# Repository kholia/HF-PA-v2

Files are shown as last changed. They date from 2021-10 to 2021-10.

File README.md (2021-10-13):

### HF-PA-v2

VU3CER's `Class-E HF PA` for https://github.com/kholia/Easy-Digital-Beacons-v1
project for 20m band and up. It has (optional) software-controlled variable PA
Output Power.

Supported bands: 80, 60, 40, 30, 20, 17m, and more bands with switchable 'LPF
Module' board.

(July 2021 Update): While this HF PA works as well as the uSDX V1.02 PA and the
QCX+ PA (they all use the same design!), we prefer our new [HF-PA-v3
system](https://github.com/kholia/HF-PA-v3/) PA for its robustness. If you
need a 3W+ @ 14 MHz with high efficiency, this Class-E HF PA design
(`HF-PA-v2`) is the best one ;)

Constraints for the initial PCB prototypes for validating the design:

- PCB is to be homebrewed (laser printer, toner tranfer using iron, etching via FeCl3)

- PCB is single-sided. Only one layer is available for routing.

- BS170 MOSFETs need to be on an edge to allow usage of heatsinks.

- My external `PA150 HF Linear Amplifier` needs 2W minimum to function.

Input: Few milliwatts is fine. Note: Si5351's output is around 8-10mW.

Output: Full-power 3.2W+ @ 13.3v (4S LiFePo4) for 20m band (14.074 MHz) with
around 45-55% efficiency *OR* Safer 2W with reasonable PWM setting for digital
modes!

Note: All screenshots are clickable and zoomable.

Note 2: Active cooling (fan) is recommended for digital modes! You have been
informed ;)

Schematic:

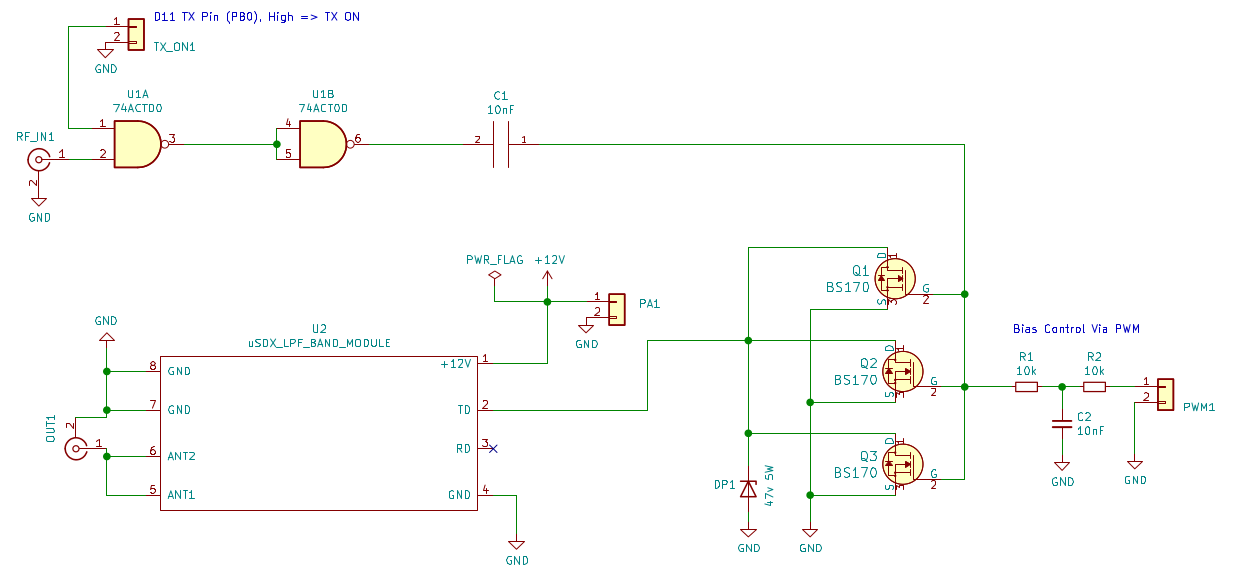
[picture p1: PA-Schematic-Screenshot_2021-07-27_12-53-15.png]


The HF PA has over-voltage ("High-SWR") protection via a `47v zener power-dumping diode`.

PCB renderings:

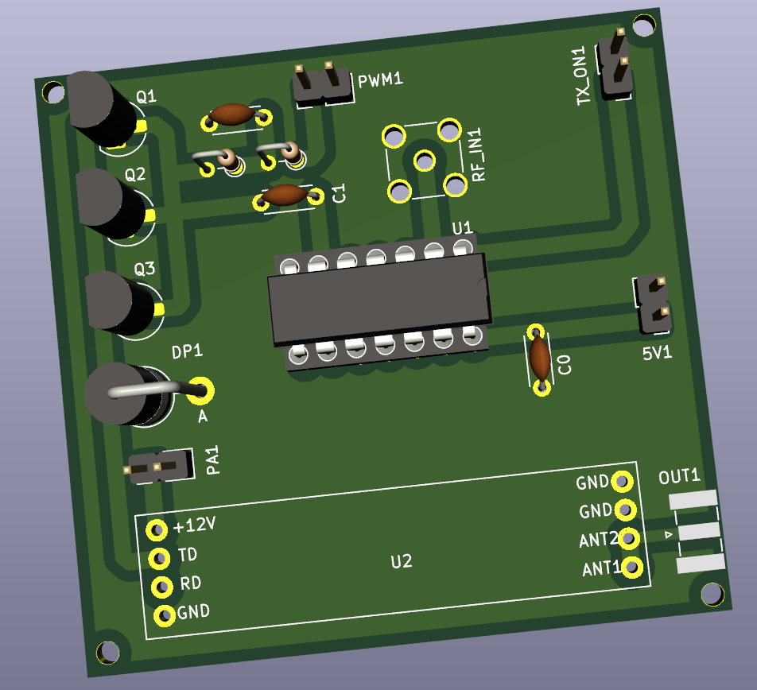
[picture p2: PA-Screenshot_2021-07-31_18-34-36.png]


Socketable version (recommended):

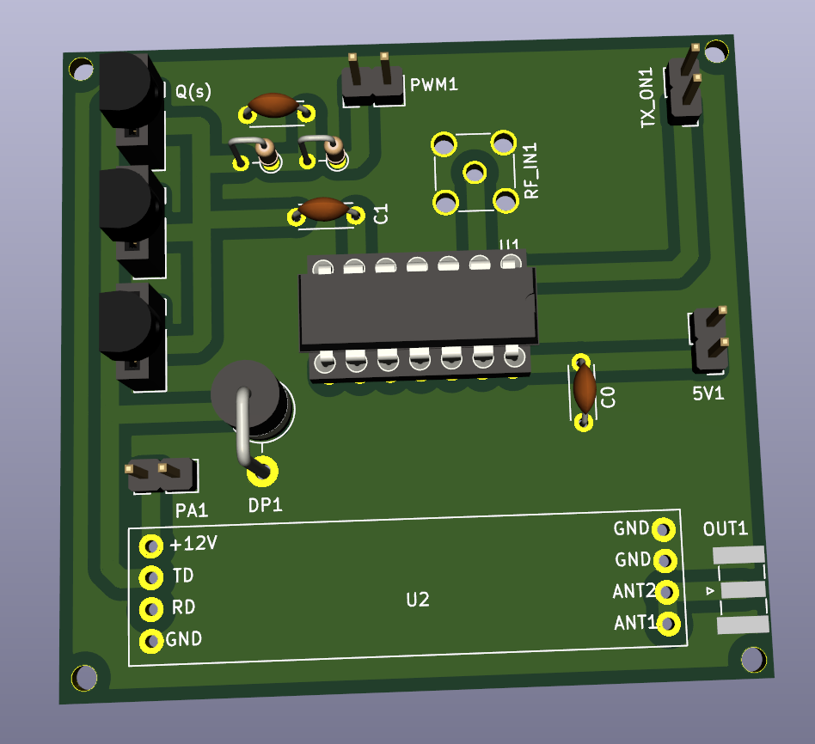
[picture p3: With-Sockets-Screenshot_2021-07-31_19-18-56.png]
HF-PA-v1 Sockets


Testing the Triple-Mode PSU + LPF 20m + 3xBS170 @ 13.8v:

HF-PA-v1 Demo
HF-PA-v1 Demo 2

LPF schematic (from uSDX PCB by WB2CBA):

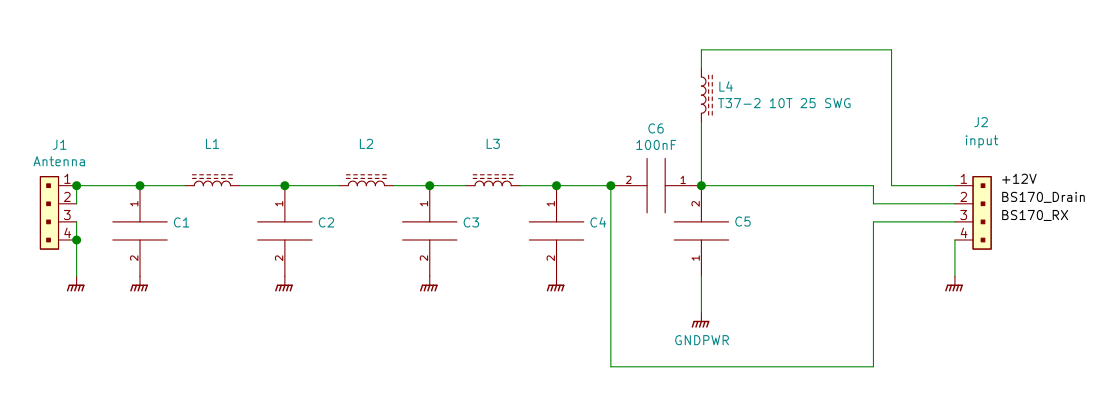
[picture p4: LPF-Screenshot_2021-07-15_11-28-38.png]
LPF 1


Safe power supply module for the PA. It has over-current protection.

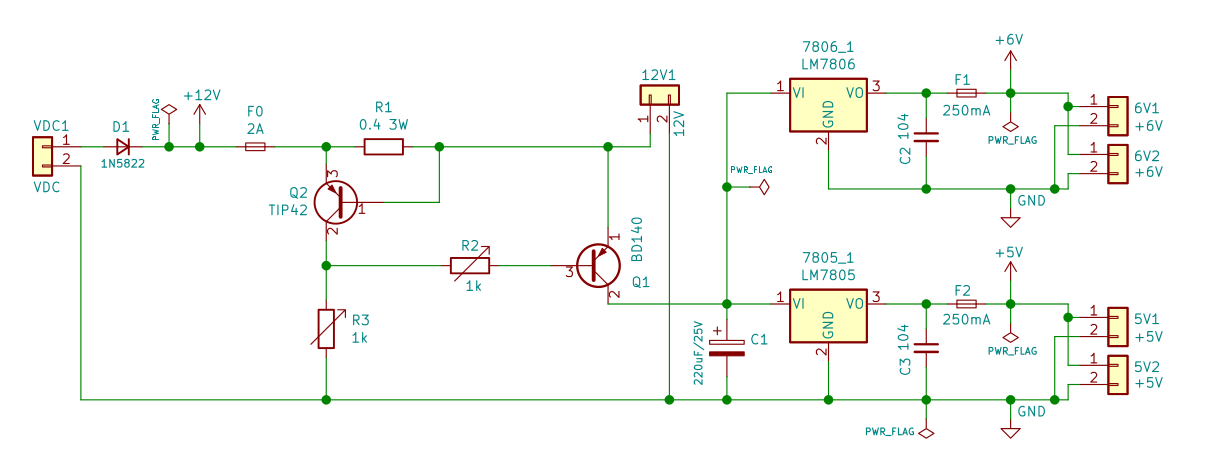
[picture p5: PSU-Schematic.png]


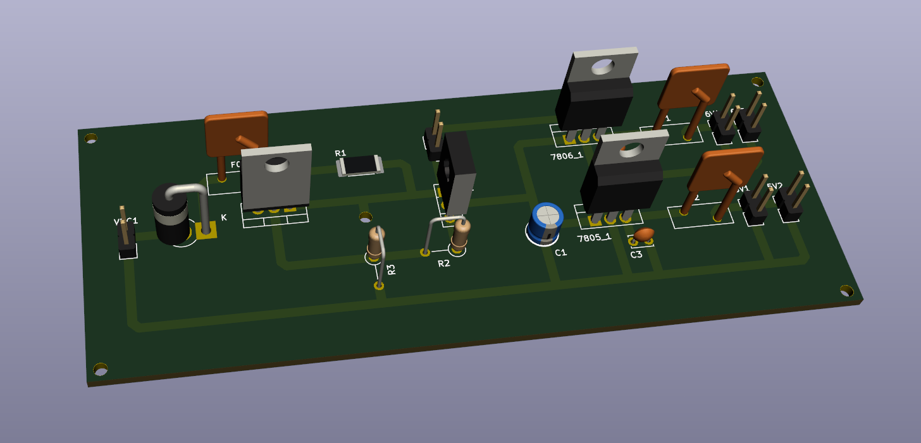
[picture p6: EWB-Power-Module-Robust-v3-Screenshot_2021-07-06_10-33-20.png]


Note: This 3D rendering is *only* published to help with the manual layout work
on Zero-PCBs.

Note 2: Various sub-circuits were simulated in LTspice prior to implementation.

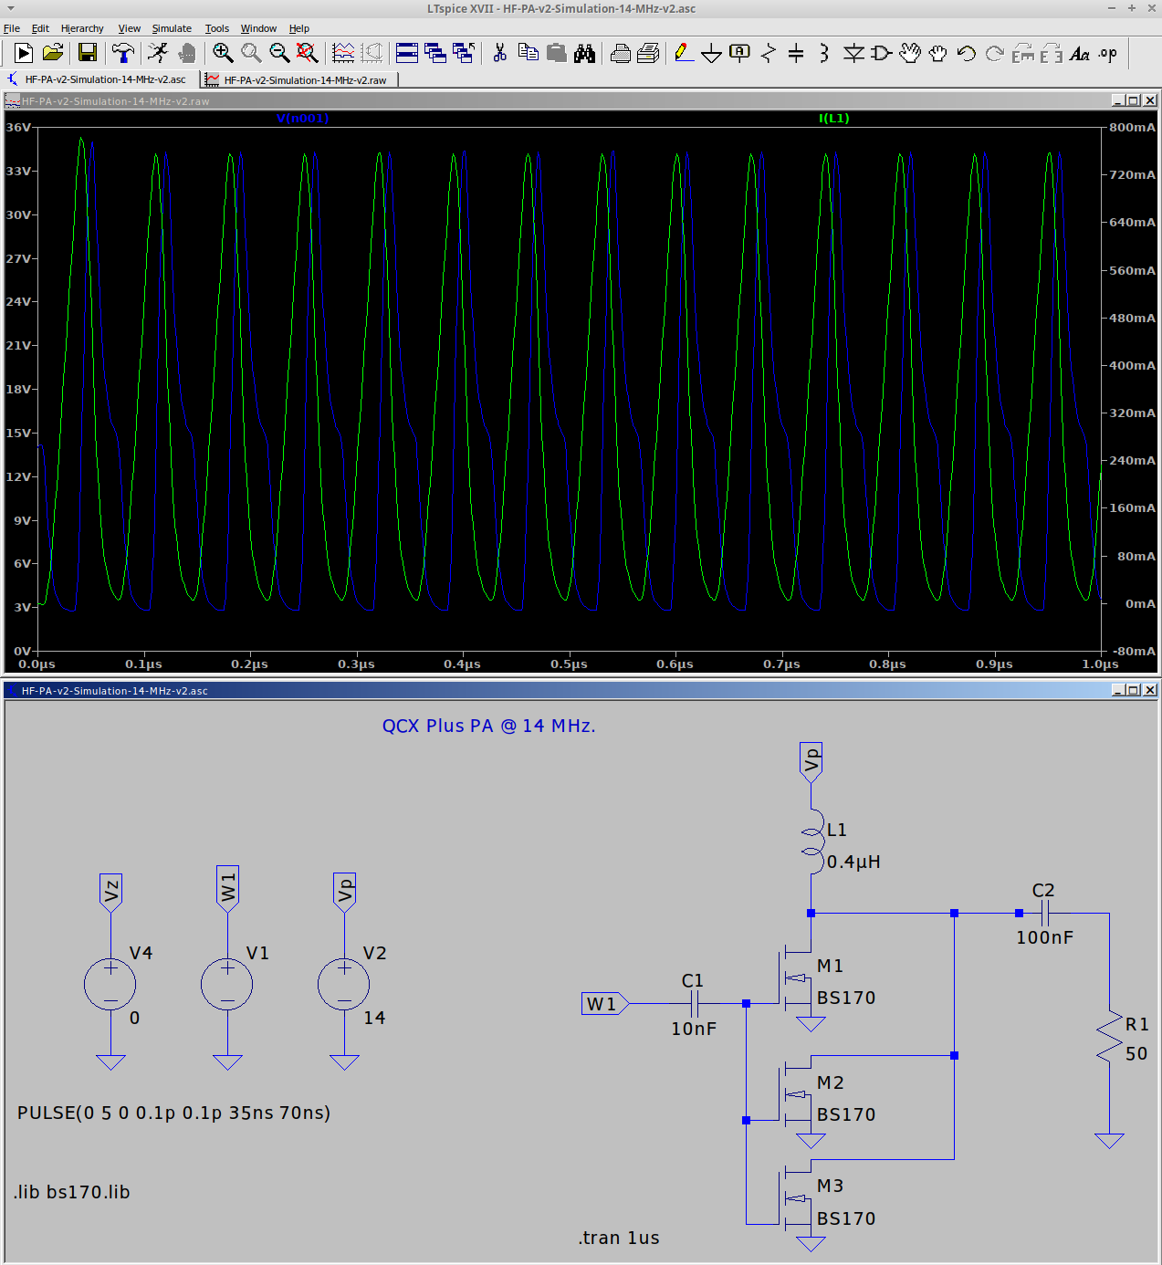
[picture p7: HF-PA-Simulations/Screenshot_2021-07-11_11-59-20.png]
Simulation 0

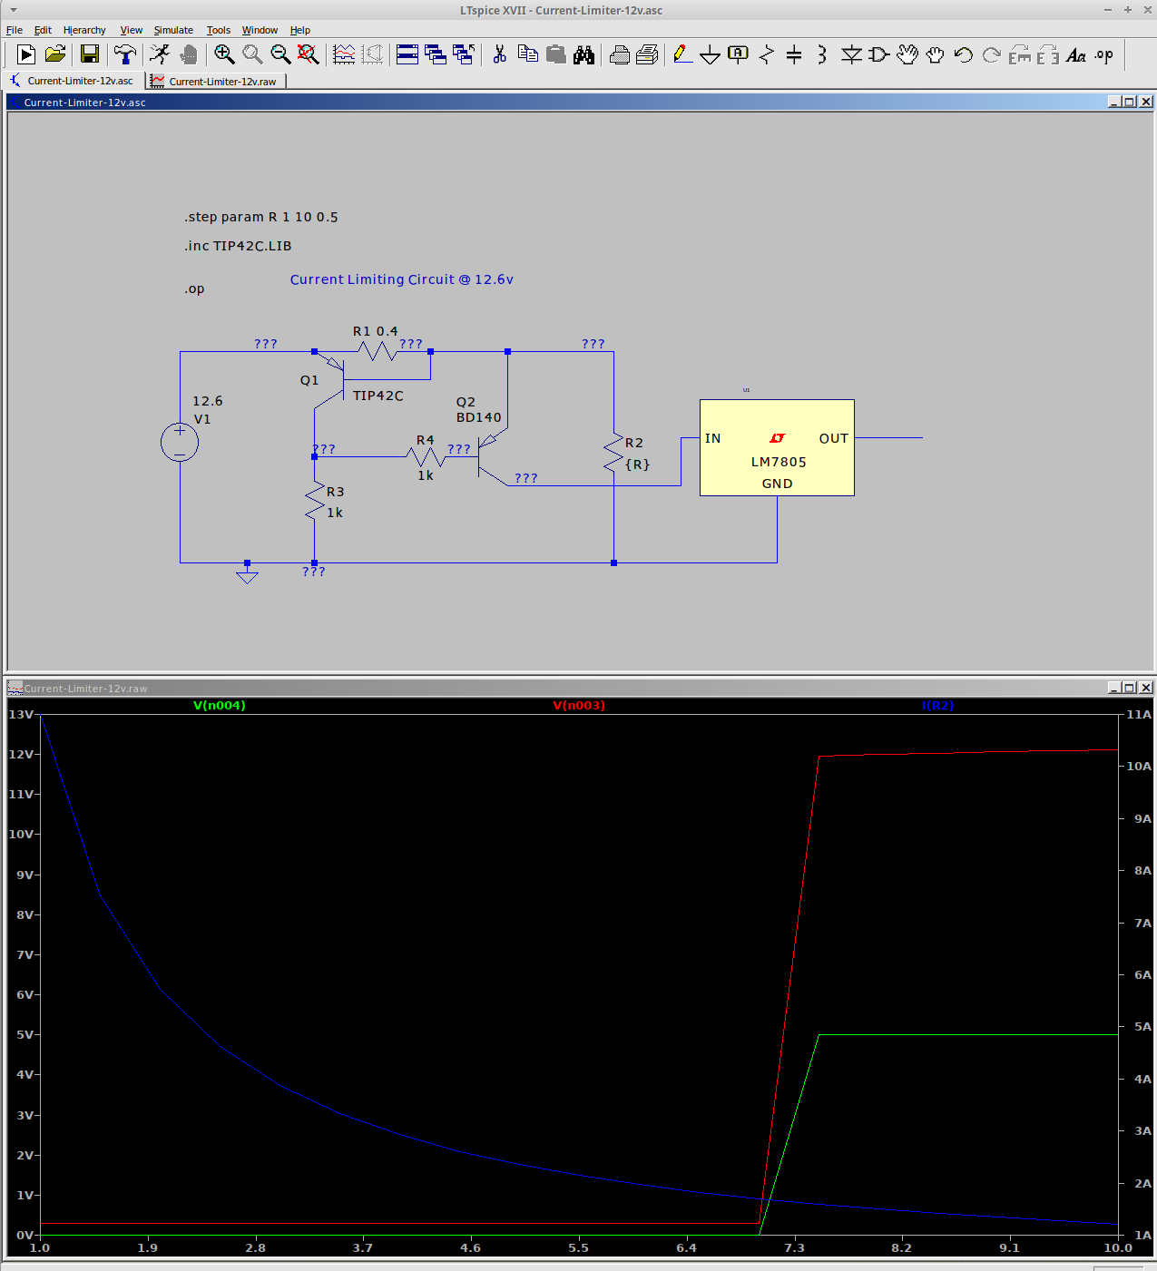
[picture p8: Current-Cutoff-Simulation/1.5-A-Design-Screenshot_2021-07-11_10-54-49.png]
Simulation 1


### Sample Code

- https://github.com/kholia/uSDX_Beacon

- https://github.com/kholia/Easy-Digital-Beacons-v1

#### O(Current consumption)

The ESP8266 usually draws a peak current of about 250mA after it wakes up and
then more or less constantly draws around 70mA before it goes back to sleep.

DS3231 -> 5mA

Si5351 -> ~50 to 100mA

Upper bound -> 1.4A maximum.

#### BOM

- 1 x SN74ACT00N (TI)

- 3 x BS170 (ON Semi)

- 1 x 7805 Voltage Regulator TO-220 (STMicroelectronics)

- 1 x 7806 Voltage Regulator TO-220 (STMicroelectronics)

- 1 x 1N5822

- 1 x 1N5368B (47V 5W Zener Diode)

- 2 x 0.2 Ohms - 3W Current Sensing Resistor

- 2 x 1k Ohm - 0.25W Metal Film Resistor

- 220uF 25v Electrolytic Capacitor

- 5 x 100nF (104) Ceramic Capacitor

- 1 x 10nF (103) Ceramic Capacitor

- 1 x BD140 Transistor

- 1 x TIP42 Darlington Transistor

- 3 x T37-6 - Yellow Toroid, 1 x T37-2 - Red Toroid (LPF)

- 2 x 180pf, 2 x 390pf, 1 x 30pF NP0 Ceramic Capacitors (LPF caps, Kemet)

- 3 meters - Copper Magnetic Winding Wire (24 AWG - 25 SWG)

- Misc: Connectors, Zero PCB, Various Consumables

- Tools: LCR-T4 Meter (for measuring things), RF Power Meter

Tip: Buy in bulk for better pricing, and for getting spares for the "junk box".

#### 20m LPF Module Details

- L1 - T37-6 / 16 turns
- L2 - T37-6 / 17 turns
- L3 - T37-6 / 16 turns
- L4 - T37-2 / 10 turns
- C1 - 180pf
- C2 - 390pf
- C3 - 390pf
- C4 - 180pf
- C5 - 30pf

Borrowed from QCX manual and uSDX WB2CBA PCB documentation.

#### BOM + Equipment Sources

- https://www.semikart.com/ (BS170, NP0 LPF caps - Kemet and others, Aavid DIP-14/16 Heat Sinks)

- https://www.semikart.com/search/SN74ACT00N

- https://robu.in/product/0-2-ohm-3w-surface-mount-sense-resistor-pack-of-3/

- https://www.electronicscomp.com/

  - BS170, regular caps, ST voltage regulators

  - TIP42, BD140

- https://www.electroncomponents.com/ (transistors, connectors, consumables, misc)

- https://www.sunrom.com/ (regular ceramic caps)

- https://projectpoint.in/

  - Transistors, regular caps, voltage regulators, MFR resistors, misc

  - Copper Magnetic Winding Wire

- https://www.bhagwatilightingindustries.com (Thermal Adhesive Paste)

- https://www.sunrom.com/p/254mm-40x1-female-socket-strip-machine-round-pins

  `SIP Sockets 1A`

- eBay (`gr_makis`) - Toroids

- [LCR-T4 LCR Meter](https://www.techtonics.in/lcr-t4-12864-lcd-graphical-transistor-tester-resistance-capacitance-esr-scr-meter)

### Notes

- The `CDIL 2N3904` TO-92 transistor has `CT2N 3904 LS` marking on it.

  `CT` -> `Continental... Device India Ltd (CDIL)`

- `Burnt` BS170 MOSFETs typically have their `Drain` and `Gate` shorted (Pin 1 and Pin 2 respectively).

- Use `SIP sockets` to avoid accidentally killing the MOSFETs via ESD (during probing, soldering, etc).

- PCB test: Remove the MOSFETS (keep everything else connected) and measure the
  resistance between the `Gate Pin` and `Ground`. It should show `OL (Open Line)`.

### Tips

- BS170 MOSFETs are very sensitive with regards to ESD and high soldering
  temperatures.

  Use best practices when dealing with BS170 MOSFETs and perhaps always ;)

#### References

- https://github.com/kholia/uSDX_Beacon
- https://github.com/agustinmartino/wsjt_transceiver
- http://hyse.org/pdf/www.aoc.nrao.edu/~pharden/hobby/_ClassDEF1.pdf
- http://hyse.org/pdf/www.aoc.nrao.edu/~pharden/hobby/_ClassDEF2.pdf
- http://thestone.zone/radio/2020/12/13/multi-watt-amplifier.html
- http://thestone.zone/radio/2020/12/18/gate-driver-amplifier.html
- http://thestone.zone/radio/2021/01/14/capacitors.html
- http://thestone.zone/radio/2021/01/16/minor-enhancements.html
- https://www.g0kla.com/scpa/SimpleCheapPA.php
- https://www.linkedin.com/pulse/rf-pcb-design-rules-manufacturing-process-lisa-chu/
- http://thestone.zone/radio/2021/06/04/attenuator.html
- http://thestone.zone/radio/2021/06/05/power-amplifier.html
- https://on7dq.blogspot.com/2020/12/qcx-mini-measurements.html
- https://www.random-science-tools.com/electronics/dBm-Watts-volts.htm
- https://www.mitsubishielectric.com/semiconductors/php/oSearch.php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
- http://www.carnut.info/WSPR_Tx/WSPR_Tx.htm
- https://sites.google.com/view/andy-g0ftd/iron-fist-transmitter
- https://www.dj0abr.de/english/technik/dds/pa.htm
- https://www.qsl.net/py2ohh/
- https://hf5l.pl/en/transceiver-usdx-with-arduino-nano/#

#### Credits

- MTR5B schematic
- PFR-3 design
- Dan Tayloe, N7VE (NC2030 PA design)
- Hans Summers (QCX+)
- Guido PE1NNZ (uSDX)
- WB2CBA (uSDX PCB)
- Tom (AK2B)
- Various uSDX folks
- Chris (G0KLA / AC2CZ) - over-current protection

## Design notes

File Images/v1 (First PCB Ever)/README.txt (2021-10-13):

"Print mirrored" was accidentally selected in KiCad! ;(

RF output for 11.5 drain voltage and 1xBS170 is ~0.5W (same as uSDX V1.02 board)

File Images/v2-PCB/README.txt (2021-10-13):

TIP: When doing a 'Zone Fills' ("ground copper pour"), increase the default
track clearance from 0.508 to 1.016. This helps a lot with homebrewing PCBs.

The "PCB v2" version uses this.

Note: (BS170) MOSFETs are easy to destroy via ESD! Using SIP sockets + a single
power supply source help in not destroying MOSFETs via ESD!

The "PCB v3" will use SIP sockets!

Use 0.8mm drill bit for making holes. Only the PCB Mount SMA connector requires
bigger drill holes.

python2 OscScreenGrabLAN.py png 192.168.1.15

Ignore the "common noise" superimposed on the output RF sine wave - we will
use better probing techniques in the future ;)

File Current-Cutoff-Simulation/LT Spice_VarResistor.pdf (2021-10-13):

Summary

## How to Simulate a Variable Resistor in LTSpice

- Ensure LT Spice is completely Maximized
- Create a circuit how you normally would, with normal resistors
- Set the value of resistor that you want to be variable, to be {R}
- Click on .op (far right on the toolbar)
- Type: .step param R 1 10k 1k (steps from 1 to 10K in 1k increments)
- You will need to fill in the correct values, based on the resistive sensor you used
- Click Simulate -> Run -> Go to the DCop pnt tab -> Click ok
- Simulation screen will pop up, click on the node you want to measure. (V out)
- Be sure to add simulations to report.

Detailed Instructions
To evaluate a circuit with respect to a changing resistance the value of the varying resistor must be defined as a variable. Students are tasked with creating a schematic of the circuit you will be analyzing, then simulate the results. See figure 1.5 in lab Section 2 for a reference. If unsure on how to create a circuit in LT spice, refer to Lab section 1 for guidance.

*Note: For the resistive sensor, a resistor component is inserted into the circuit and modified.

Once the circuit has been created and all the static components (one those don’t change values) have been defined, modify the component that is intended to be a variable resistor by doing the following: Right click on the component and enter the variable name inside of curly brackets. In the following example the value of R3 has been defined as the variable R.

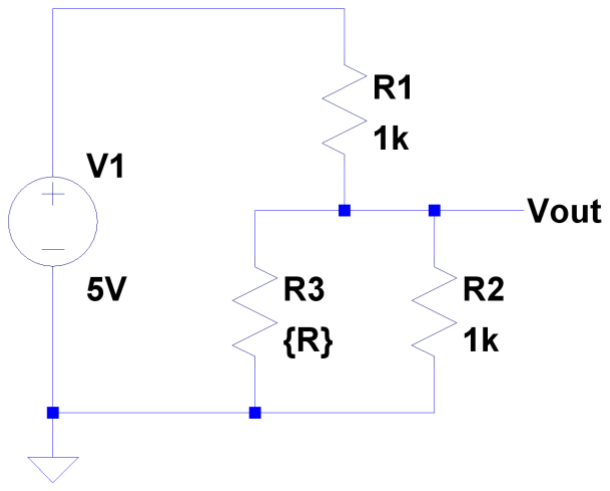
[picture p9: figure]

Figure 1: sample of a resistor circuit with a resistive sensor, R3 that has t the Value: {R}

Once the resistor value has been modified, locate the .op button on the far right of the tool bar. (if LTSpice is not maximized, you may not see this button, so expand to window). In the .op window you will need to type the following:

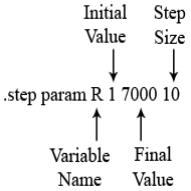
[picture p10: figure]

Determine what resistance to start at, what resistance to stop at, and how much will it increment.

*Note: the start value has to be strictly greater than 0.

In words this command tells LTSpice that there is a variable named R that has an initial value of 1 and a final value of 7000 and to evaluate the circuit from 1 to 7000 in increments of 10.
Now that the variable has been defined, a DC operating point simulation is used to evaluate the circuit. In the same textbox press “Ctrl-M” to start a new line and enter “.op” At this point the “Edit Text on the Schematic:” textbox should contain the following:

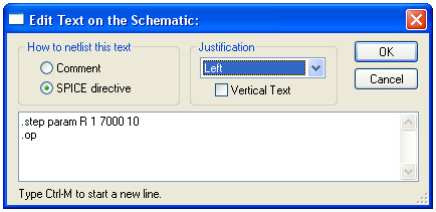
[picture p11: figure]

Click “OK” and place the command in an open area on the schematic.

Figure 2: GUI for editing component behavior.

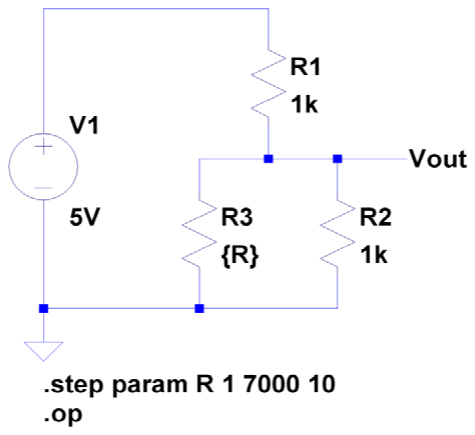
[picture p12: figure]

Simulation

Once the circuit is complete, go to the tool bar and click on simulate -> run (or right click-> run), go to the ‘ DCop pnt’ tab and click ok. The simulation window will pop up. Click on a node to see the output voltage. Click on a component to see amount of current flowing through it at a given point in time.

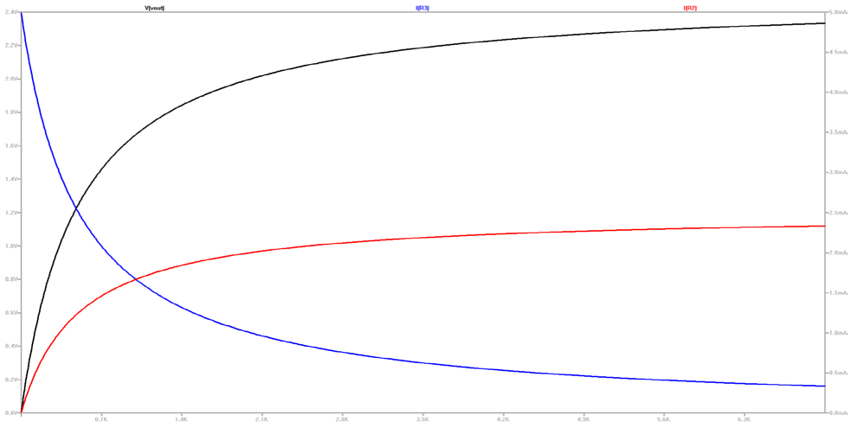
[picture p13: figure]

*Note: To change the background color of the schematic, go to the toolbar and Click Tools -> Color preference. In the scroll down menu, select background and change the color to white.

Figure2: schematic of resistor circuit use as an example simulating a resistive sensor in LTSpice

Figure: Example simulation output of resistor circuit.

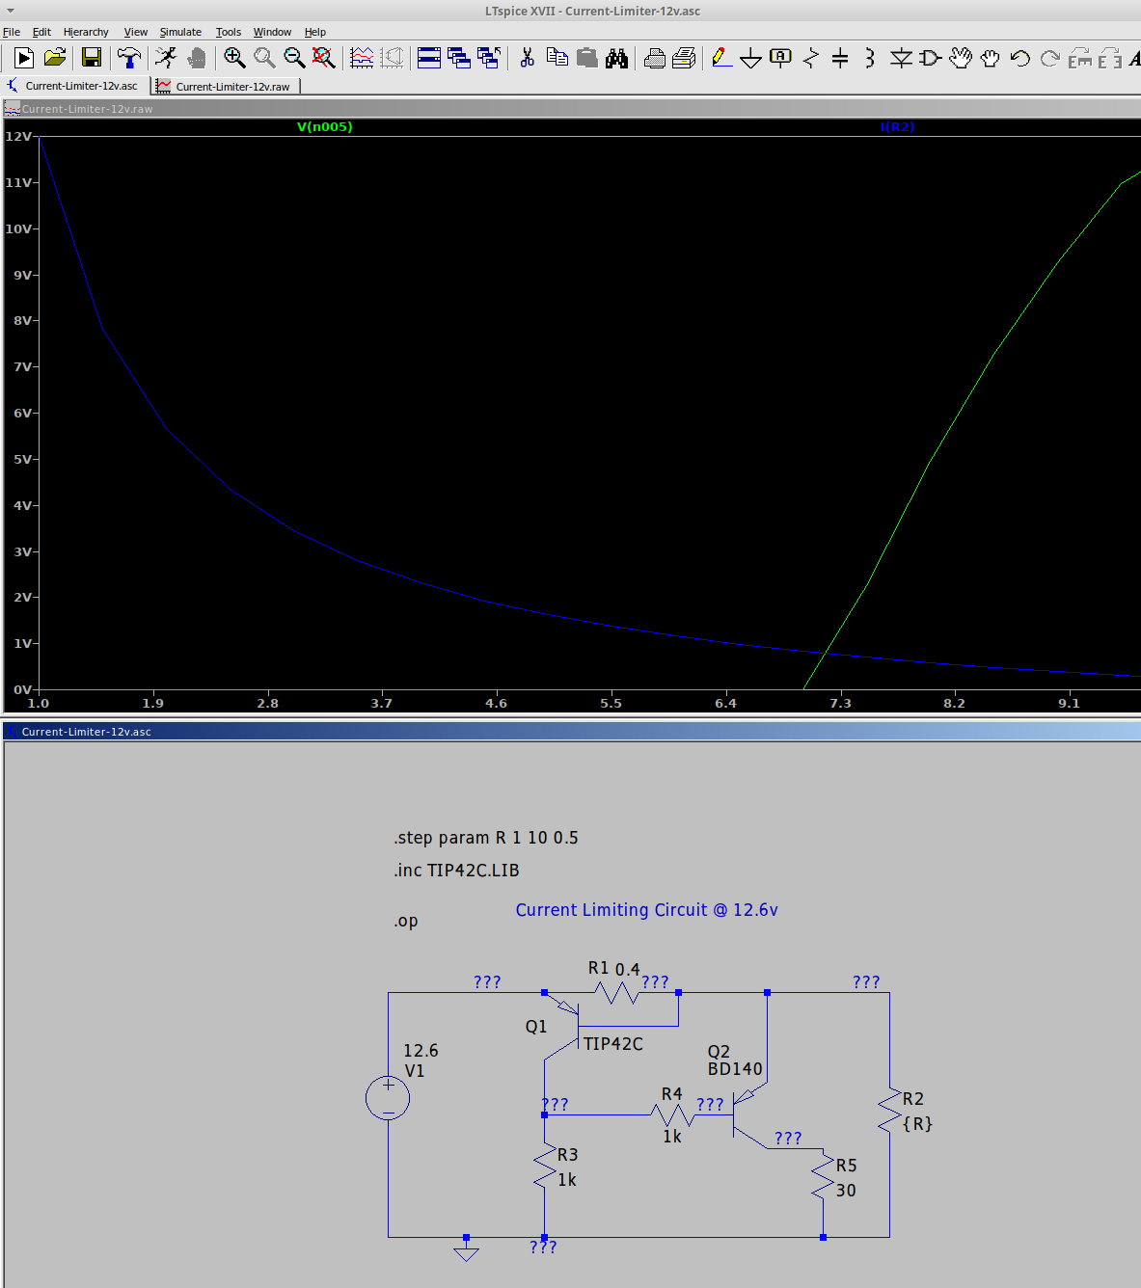
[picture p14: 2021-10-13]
Current-Cutoff-Simulation/[1.5A Design] Screenshot_2021-07-11_10-30-56.png

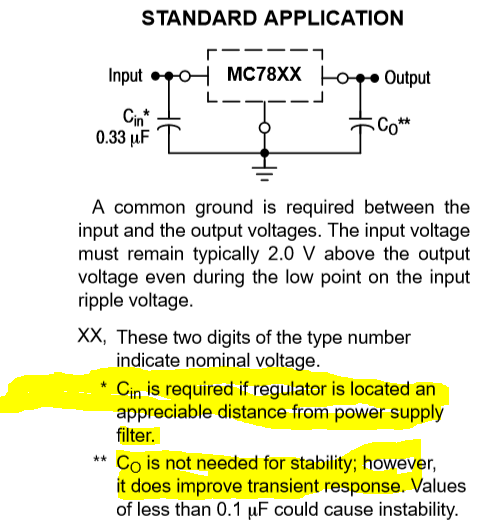
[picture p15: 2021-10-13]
datasheets/7805 Output Capacitor Requirement.png

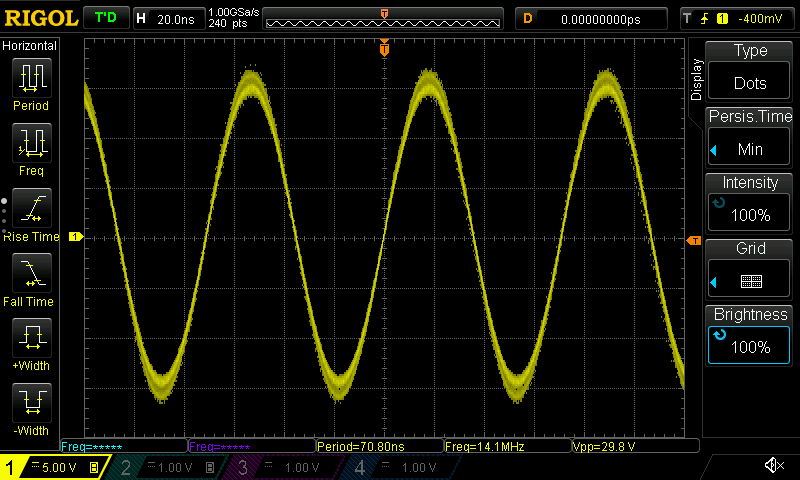
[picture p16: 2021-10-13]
Images/v2-PCB/DS1054Z_DS1ZA203916662_2021-07-31_20.33.57.png

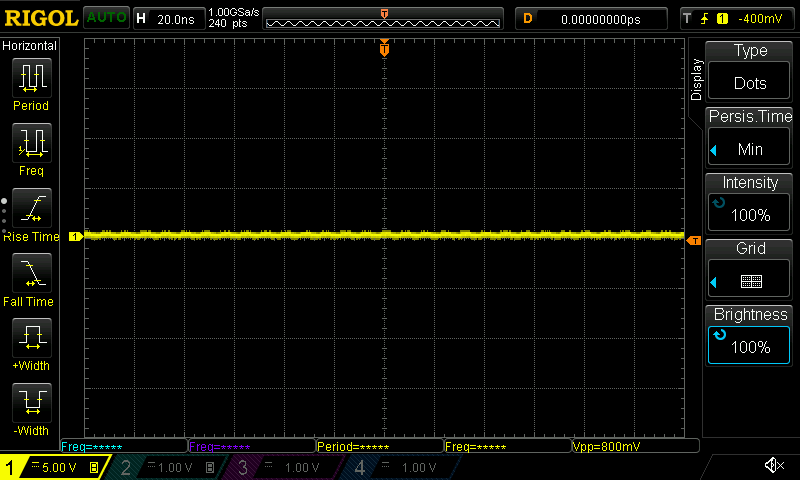
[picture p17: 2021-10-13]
Images/v2-PCB/DS1054Z_DS1ZA203916662_2021-07-31_20.35.18.png

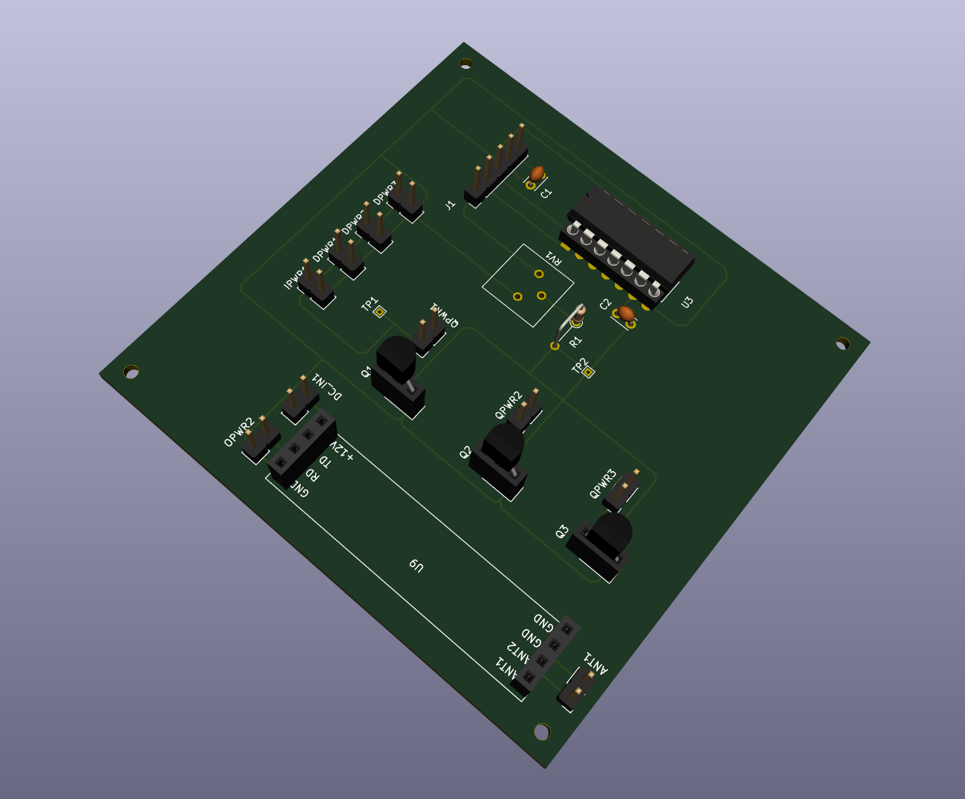
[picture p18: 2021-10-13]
PA+LPF Combo.png

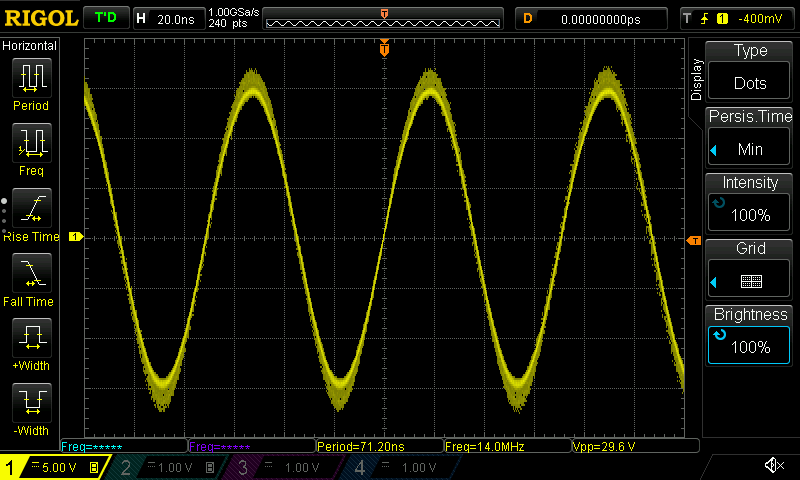
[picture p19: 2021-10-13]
Images/v2-PCB/DS1054Z_DS1ZA203916662_2021-07-31_20.31.40.png

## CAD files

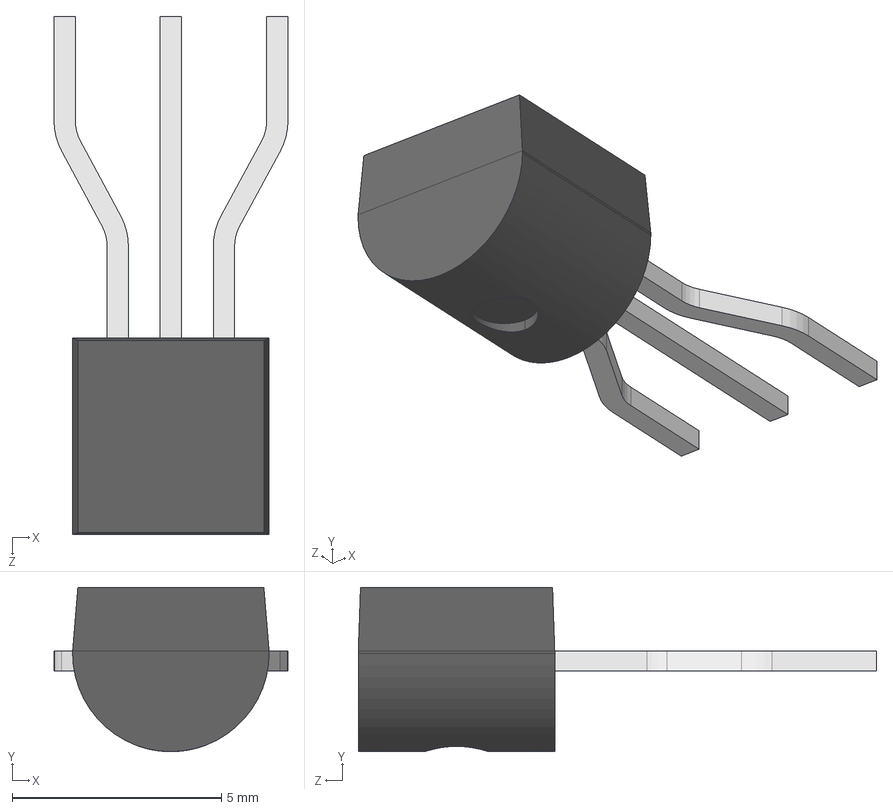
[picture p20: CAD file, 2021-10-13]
HF-PA-v2-Socketed/models/User Library-TO-92-2_54-line.STEP
5.60 x 3.93 x 12.4 mm
User Library-TO-92 Version2_TO-92 Part1
User Library-TO-92 Version2_TO-92 Part3
User Library-TO-92 Version2_TO-92 Part4
User Library-TO-92 Version2_TO-92 Part5

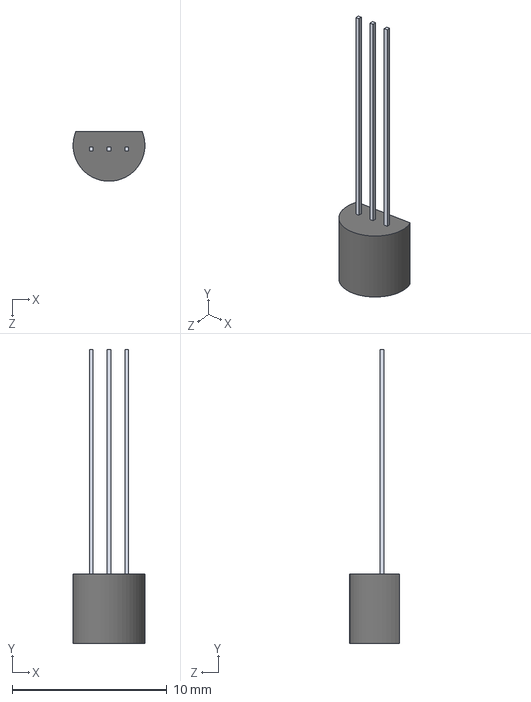
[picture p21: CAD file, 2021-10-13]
HF-PA-v2/models/Transistor_TO-92_Type.STEP
4.64 x 19.0 x 3.20 mm

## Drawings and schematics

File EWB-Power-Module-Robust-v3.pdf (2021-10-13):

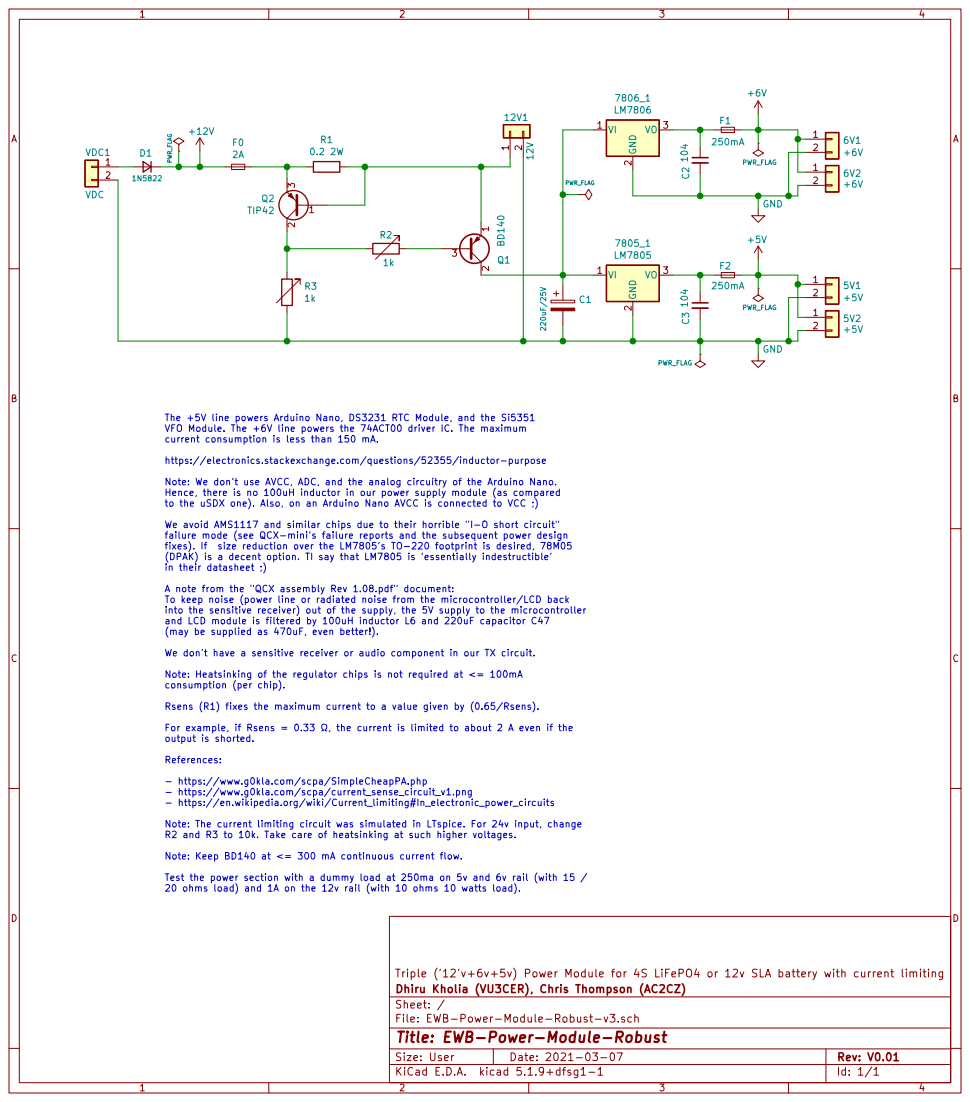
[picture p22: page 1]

VFO Module. The +6V line powers the 74ACT00 driver IC. The maximum
current consumption is less than 150 mA.

https://electronics.stackexchange.com/questions/52355/inductor-purpose

Note: We don't use AVCC, ADC, and the analog circuitry of the Arduino Nano.
Hence, there is no 100uH inductor in our power supply module (as compared
to the uSDX one). Also, on an Arduino Nano AVCC is connected to VCC ;)

We avoid AMS1117 and similar chips due to their horrible "I-O short circuit"
failure mode (see QCX-mini's failure reports and the subsequent power design
fixes). If size reduction over the LM7805's TO-220 footprint is desired, 78M05
(DPAK) is a decent option. TI say that LM7805 is 'essentially indestructible'
in their datasheet ;)

A note from the "QCX assembly Rev 1.08.pdf" document:
To keep noise (power line or radiated noise from the microcontroller/LCD back
into the sensitive receiver) out of the supply, the 5V supply to the microcontroller
and LCD module is filtered by 100uH inductor L6 and 220uF capacitor C47
(may be supplied as 470uF, even better!).

We don't have a sensitive receiver or audio component in our TX circuit.

Note: Heatsinking of the regulator chips is not required at <= 100mA
consumption (per chip).

Rsens (R1) fixes the maximum current to a value given by (0.65/Rsens).

For example, if Rsens = 0.33 , the current is limited to about 2 A even if the
output is shorted. References: - https://www.g0kla.com/scpa/SimpleCheapPA.php

- https://www.g0kla.com/scpa/current_sense_circuit_v1.png
- https://en.wikipedia.org/wiki/Current_limiting#In_electronic_power_circuits

Note: The current limiting circuit was simulated in LTspice. For 24v input, change
R2 and R3 to 10k. Take care of heatsinking at such higher voltages.

Note: Keep BD140 at <= 300 mA continuous current flow.

Test the power section with a dummy load at 250ma on 5v and 6v rail (with 15 /
20 ohms load) and 1A on the 12v rail (with 10 ohms 10 watts load).

Triple ('12'v+6v+5v) Power Module for 4S LiFePO4 or 12v SLA battery with current limiting
Id: 1/1 Title: EWB-Power-Module-Robust File: EWB-Power-Module-Robust-v3.sch Sheet: / Dhiru Kholia (VU3CER), Chris Thompson (AC2CZ)

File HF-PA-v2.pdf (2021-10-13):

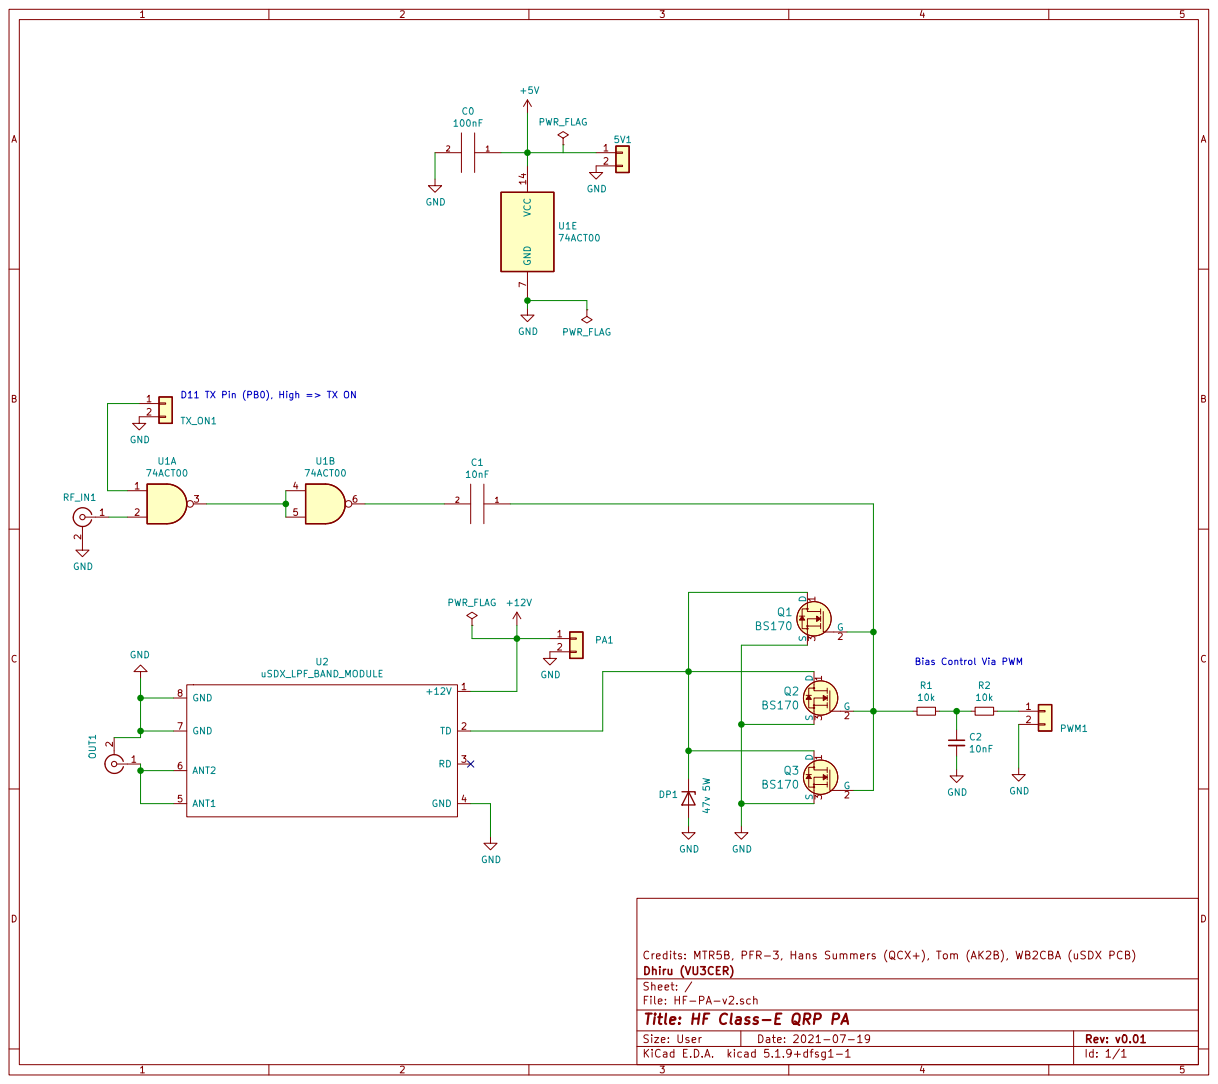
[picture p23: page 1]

D11 TX Pin (PB0), High => TX ON

Credits: MTR5B, PFR-3, Hans Summers (QCX+), Tom (AK2B), WB2CBA (uSDX PCB) D

File: HF-PA-v2.sch Sheet: / Dhiru (VU3CER)

Id: 1/1 Title: HF Class-E QRP PA

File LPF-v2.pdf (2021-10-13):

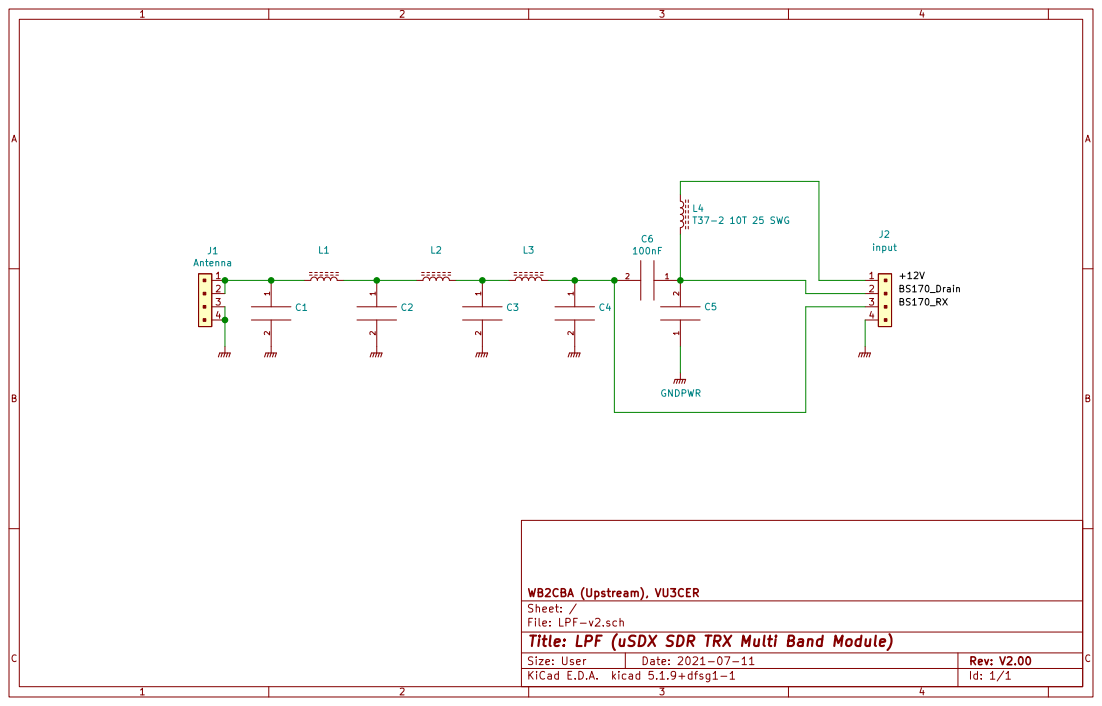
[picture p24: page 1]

Id: 1/1 Title: LPF (uSDX SDR TRX Multi Band Module) File: LPF-v2.sch Sheet: / WB2CBA (Upstream), VU3CER

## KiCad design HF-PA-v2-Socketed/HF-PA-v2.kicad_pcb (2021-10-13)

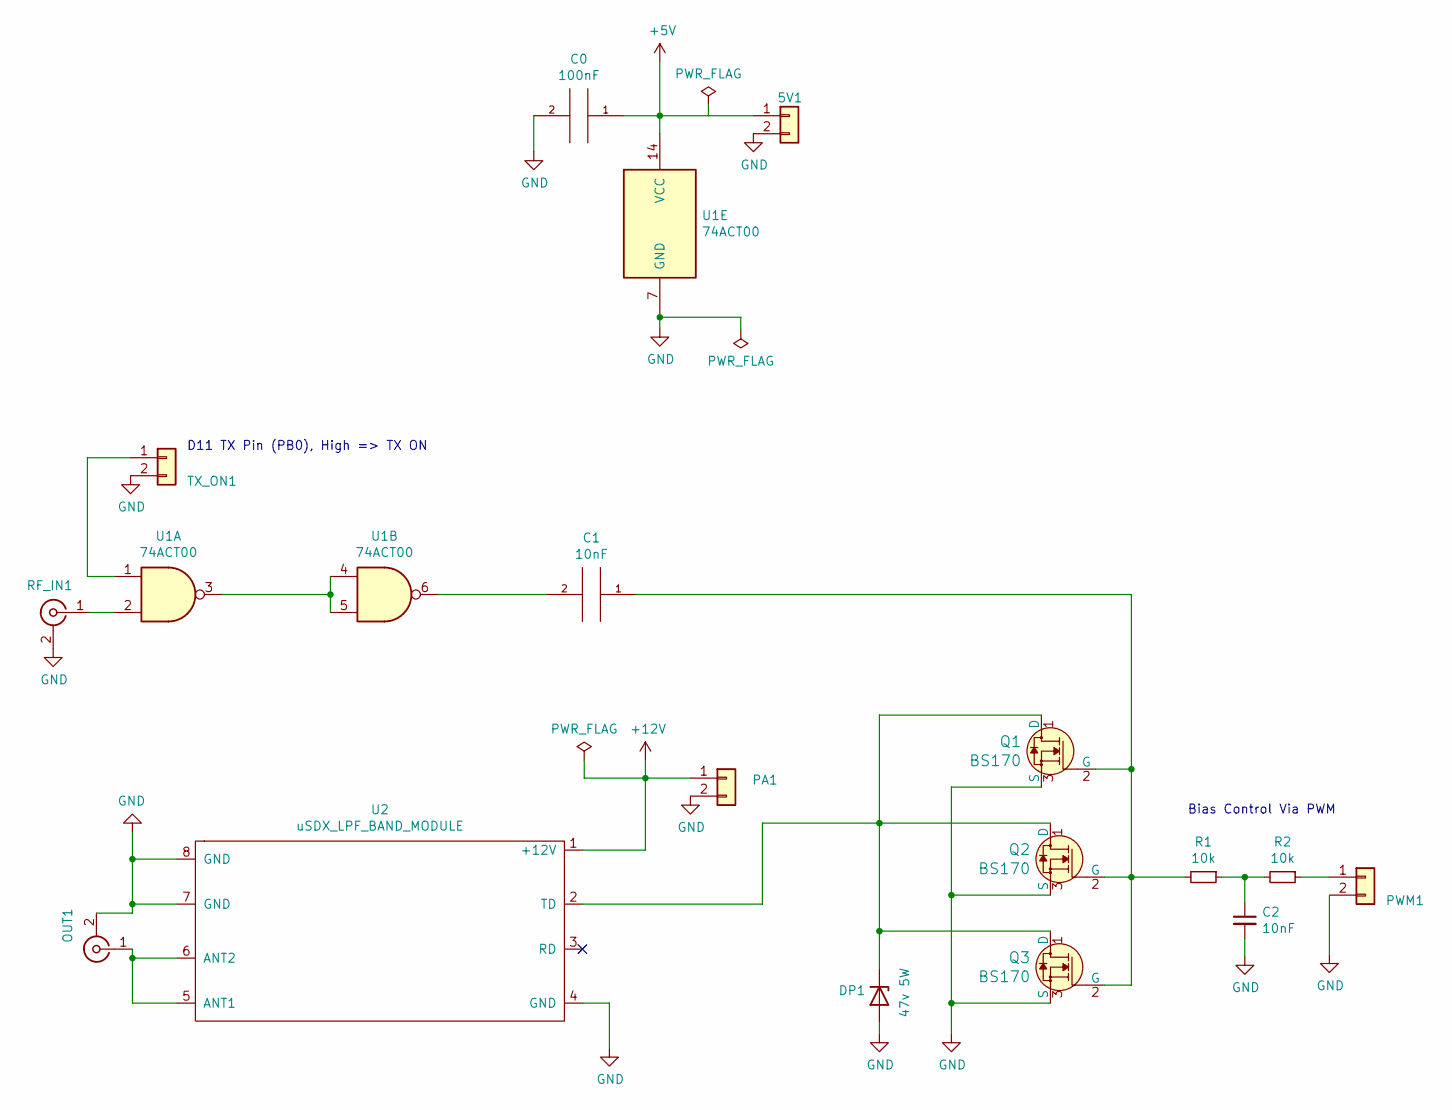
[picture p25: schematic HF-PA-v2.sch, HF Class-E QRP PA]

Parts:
5V1: Conn_01x02; PinHeader_1x02_P2.54mm_Vertical
C0: 100nF; C_Disc_D4.3mm_W1.9mm_P5.00mm
C1, C2: 10nF; C_Disc_D4.3mm_W1.9mm_P5.00mm
DP1: 47v 5W; D_DO-201_P5.08mm_Vertical_AnodeUp
OUT1: Conn_Coaxial; SMA_Samtec_SMA-J-P-X-ST-EM1_EdgeMount
PA1: Conn_01x02; PinHeader_1x02_P2.54mm_Vertical
PWM1: Conn_01x02; PinHeader_1x02_P2.54mm_Vertical
Q1, Q2, Q3: BS170; PinSocket_1x03_P2.54mm_Vertical; MPN BS170; Digi-Key_PN BS170-ND
R1, R2: 10k; R_Axial_DIN0204_L3.6mm_D1.6mm_P2.54mm_Vertical
RF_IN1: Conn_Coaxial; SMA_Amphenol_901-144_Vertical
TX_ON1: Conn_01x02; PinHeader_1x02_P2.54mm_Vertical
U1: 74ACT00; DIP-14_W7.62mm_LongPads
U2: uSDX_LPF_BAND_MODULE; uSDX_LPF_Band_Module

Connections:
+5V: 5V1.1, C0.1, U1.14 (VCC)
+12V: PA1.1, U2.1 (+12V)
GND: 5V1.2, C0.2, C2.2, DP1.2 (A), OUT1.2 (Ext), PA1.2, PWM1.2, Q1.3 (S), Q2.3 (S), Q3.3 (S), RF_IN1.2 (Ext), TX_ON1.2, U1.7 (GND), U2.4 (GND), U2.7 (GND), U2.8 (GND); also elsewhere on the board
unnamed 3: C1.1, Q1.2 (G), Q2.2 (G), Q3.2 (G), R1.2; also elsewhere on the board
unnamed: C1.2, U1.6
unnamed: C2.1, R1.1, R2.2
unnamed 6: DP1.1 (K), Q1.1 (D), Q2.1 (D), Q3.1 (D), U2.2 (TD); also elsewhere on the board
unnamed: OUT1.1 (In), U2.5 (ANT1), U2.6 (ANT2)
unnamed: PWM1.1, R2.1
unnamed: RF_IN1.1 (In), U1.2
unnamed: TX_ON1.1, U1.1
unnamed: U1.3, U1.4, U1.5

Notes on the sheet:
D11 TX Pin (PB0), High => TX ON
Bias Control Via PWM

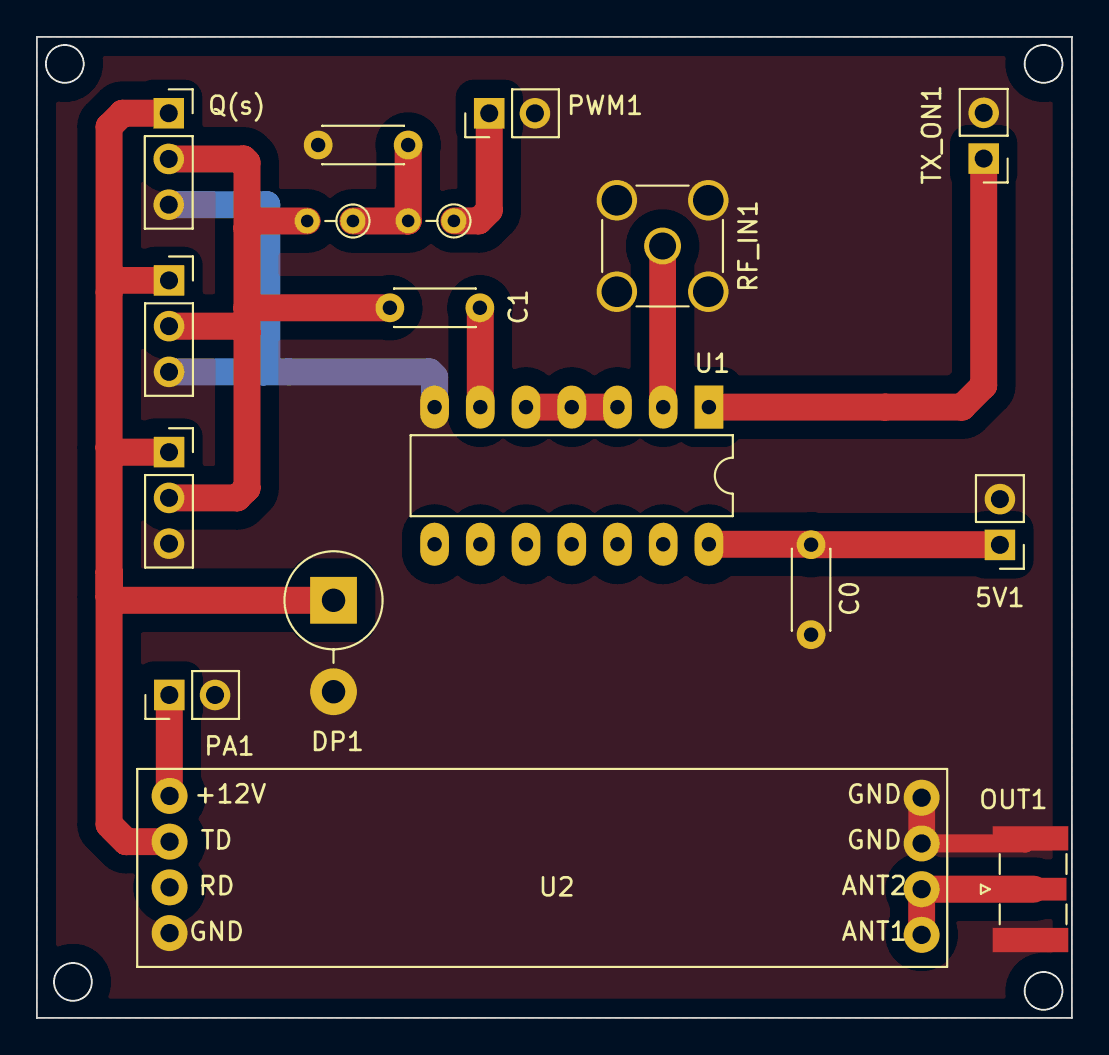
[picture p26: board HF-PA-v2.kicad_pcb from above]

Board: 2 copper layers, 57.5 x 54.5 mm, 17 parts (0 on the bottom side), 12 nets.

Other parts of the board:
Q(s): BS170; PinSocket_1x03_P2.54mm_Vertical

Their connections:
GND: Q(s).3; also elsewhere on the board
unnamed 3: Q(s).2; also elsewhere on the board
unnamed 6: Q(s).1; also elsewhere on the board

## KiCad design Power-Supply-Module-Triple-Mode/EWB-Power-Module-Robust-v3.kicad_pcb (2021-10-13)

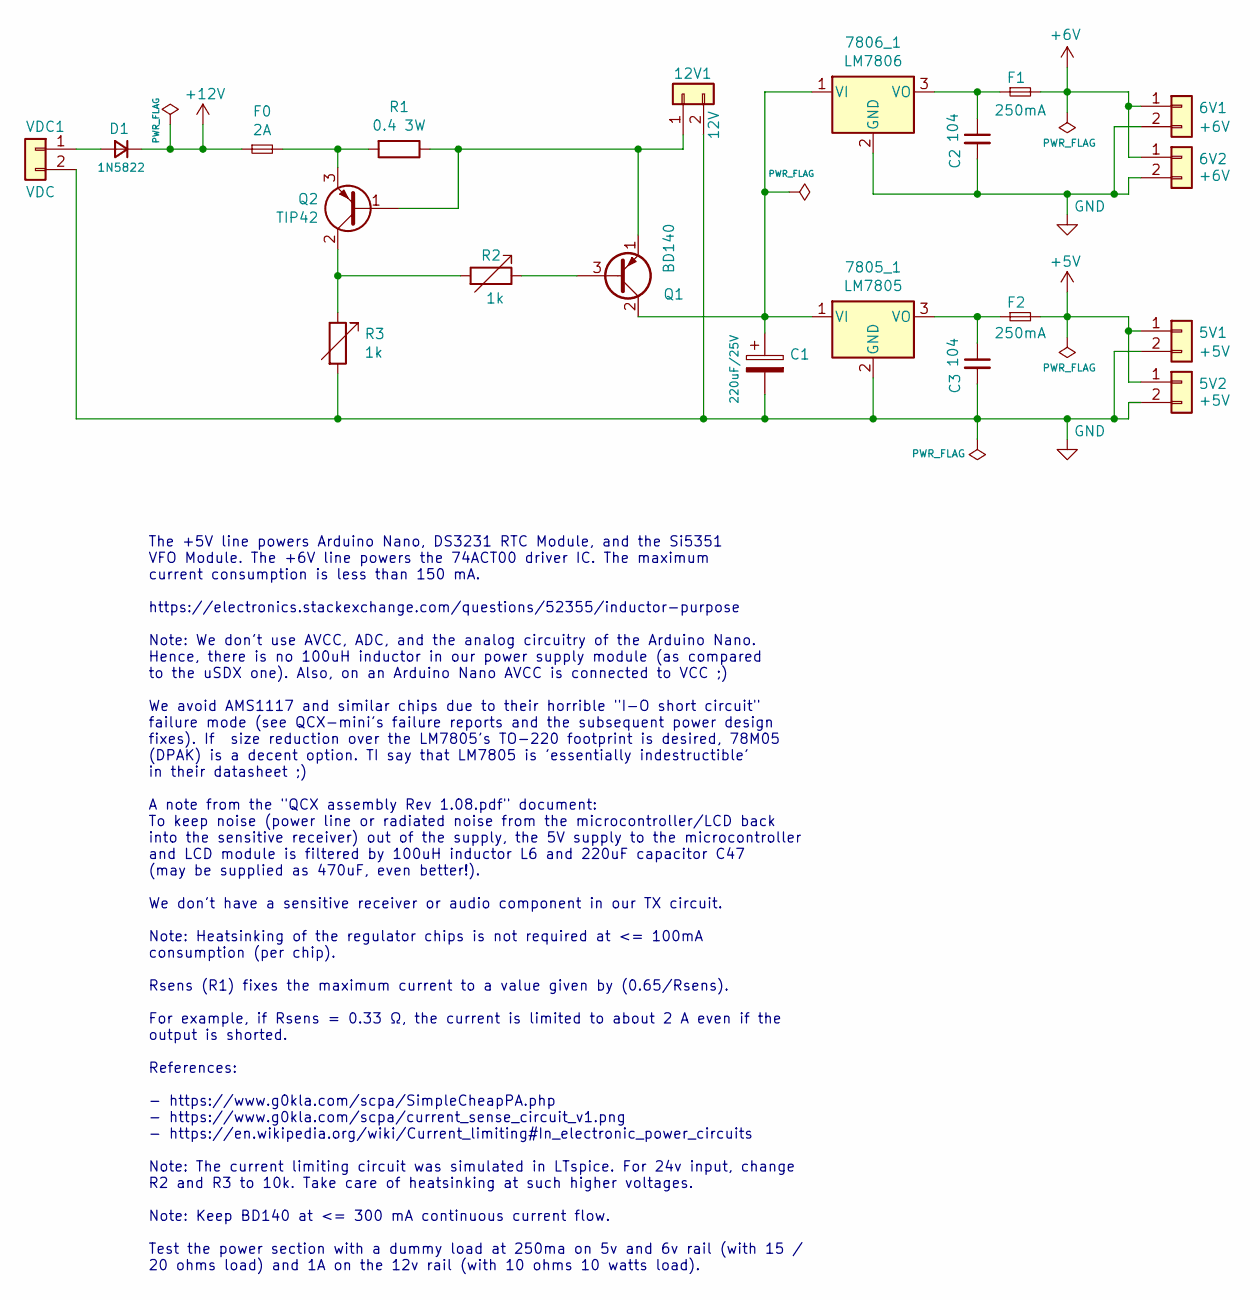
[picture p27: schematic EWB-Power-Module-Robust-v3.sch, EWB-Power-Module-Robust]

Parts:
5V1, 5V2: +5V; PinHeader_1x02_P2.54mm_Vertical
6V1, 6V2: +6V; PinHeader_1x02_P2.54mm_Vertical
12V1: 12V; PinHeader_1x02_P2.54mm_Vertical
7805_1: LM7805; TO-220-3_Vertical
7806_1: LM7806; TO-220-3_Vertical
C1: 220uF/25V; CP_Radial_D5.0mm_P2.50mm
C2, C3: 104; C_Disc_D3.4mm_W2.1mm_P2.50mm
D1: 1N5822; D_DO-201AD_P3.81mm_Vertical_KathodeUp
F0: 2A; Fuse_BelFuse_0ZRE0025FF_L9.6mm_W3.8mm
F1, F2: 250mA; Fuse_BelFuse_0ZRE0025FF_L9.6mm_W3.8mm
Q1: BD140; TO-126-3_Vertical
Q2: TIP42; TO-220-3_Vertical
R1: 0.4 3W; R_2512_6332Metric_Pad1.40x3.35mm_HandSolder
R2, R3: 1k; R_Axial_DIN0207_L6.3mm_D2.5mm_P5.08mm_Vertical
VDC1: VDC; PinHeader_1x02_P2.54mm_Vertical

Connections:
+5V: 5V1.1, 5V2.1, F2.2
+6V: 6V1.1, 6V2.1, F1.2
+12V: D1.1 (K), F0.1
GND: 5V1.2, 5V2.2, 6V1.2, 6V2.2, 12V1.2, 7805_1.2 (GND), 7806_1.2 (GND), C1.2, C2.2, C3.2, R3.2, VDC1.2
unnamed: 12V1.1, Q1.1 (E), Q2.1 (B), R1.1
unnamed: 7805_1.1 (VI), 7806_1.1 (VI), C1.1, Q1.2 (C)
unnamed: 7805_1.3 (VO), C3.1, F2.1
unnamed: 7806_1.3 (VO), C2.1, F1.1
unnamed: D1.2 (A), VDC1.1
unnamed: F0.2, Q2.3 (E), R1.2
unnamed: Q1.3 (B), R2.1
unnamed: Q2.2 (C), R2.2, R3.1

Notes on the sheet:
The +5V line powers Arduino Nano, DS3231 RTC Module, and the Si5351 VFO Module. The +6V line powers the 74ACT00 driver IC. The maximum current consumption is less than 150 mA. https://electronics.stackexchange.com/questions/52355/inductor-purpose Note: We don't use AVCC, ADC, and the analog circuit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

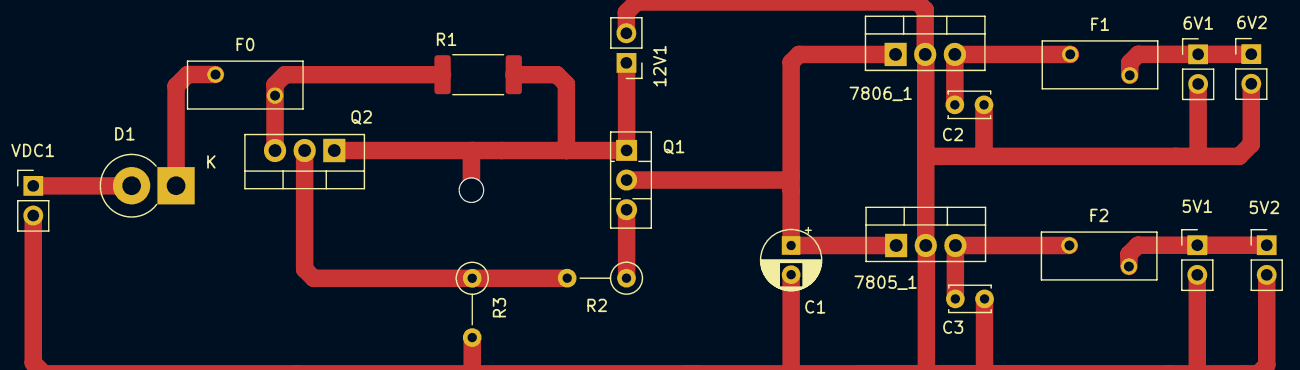
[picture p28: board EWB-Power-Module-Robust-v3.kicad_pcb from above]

Board: 2 copper layers, 20 parts (0 on the bottom side), 12 nets.
